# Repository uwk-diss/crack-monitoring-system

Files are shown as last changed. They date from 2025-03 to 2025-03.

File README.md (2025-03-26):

# Open Source Low-cost IoT Crack Monitoring Sensor System

## Introduction

Cracks in buildings and infrastructure can pose safety risks if left unmonitored. Traditional commercial solutions can be prohibitively expensive, so this project was created to provide a cost-effective alternative. Here, you will find open-source hardware designs, firmware, and backend software needed to set up a complete, network-connected crack monitoring solution.

This project provides two different sensor designs for monitoring the width of existing cracks:
- A 3D-printable long range **draw-wire sensor** using a magnetic encoder and custom PCB.
- A **digital dial indicator sensor (shahe sensor)** offering reliable and accurate readings using a off the shelf digital dial indictor of the brand SHAHE.

Both sensors are designed to operate on battery power with LoRaWAN connectivity, and a corresponding backend is provided to visualize data in real-time using MQTT, InfluxDB, and Grafana. The goal is to make structural health monitoring both accessible and affordable.

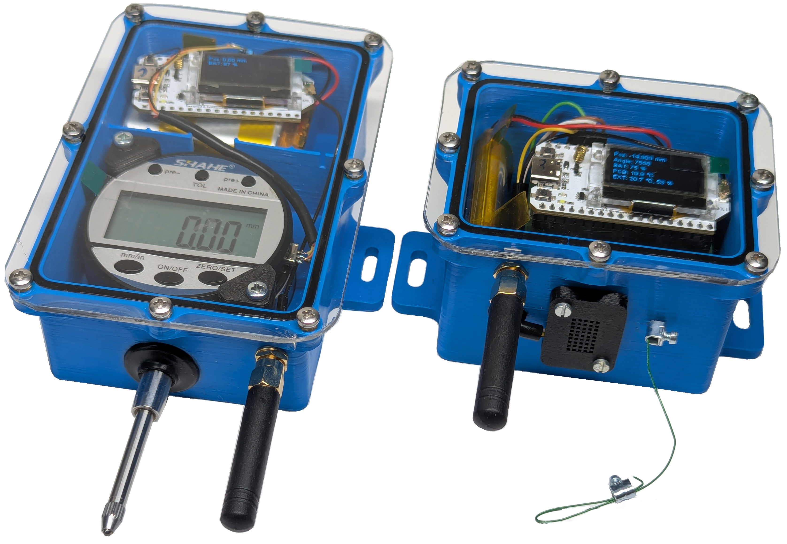
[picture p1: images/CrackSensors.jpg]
Shahe digital gauge sensor (left) and Draw-wire sensor (right)

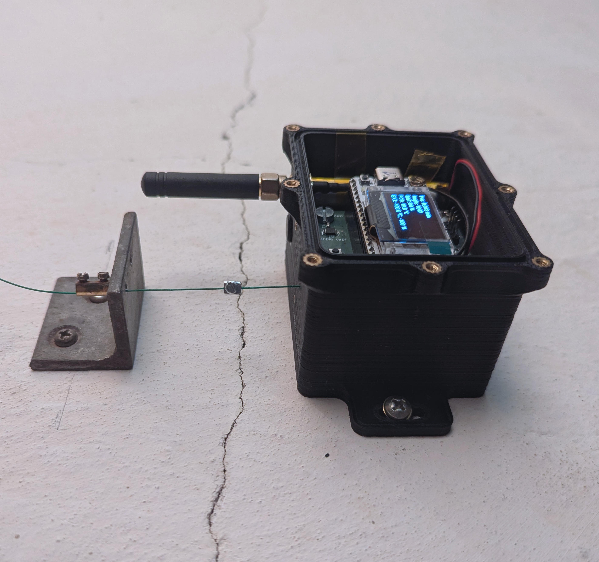
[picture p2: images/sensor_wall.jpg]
Sensor mounted on a wall


## Hardware Overview and Specifications

Block diagram of hardware

The main communication module for both sensors is the **Heltec WiFi LoRa 32 (V3)**, which supports a deep sleep current of approximately **21 µA**. Beyond the LoRa radio, it also integrates an OLED display and a Li-ion battery charging and protection circuit.

For the **draw-wire sensor**, the temperature, humidity, and hall angle sensors connect via I²C. Meanwhile, the **digital dial indicator sensor** uses a proprietary serial protocol, read through a customized USB OTG cable.

### Sensor specs:

| Parameter | Draw-Wire Sensor | SHAHE Sensor |
|---|---|---|
| Measurement Range | 55 mm | 26 mm |
| Resolution | 16 µm | 10 µm |
| Absolute Accuracy | 96 µm | 10 µm |
| Repeatability | ±16 µm | ±10 µm |
| Temperature Dependence  | 5 µm/°C* | 0 µm/°C |
| Position drift | yes** | no |
| Battery Life | ~11 months | ~11 months |
| Material Cost (excluding VAT) | ~€48.50 | ~€65 |

*Temperature compensation of the draw-wire sensor is not implemented yet.

**During a 7-week long-term test, the draw-wire sensor exhibited a permanent position offset of more than 0.1 mm. This requires further investigation.

## Communication and Backend
The sensor data is transmitted hourly via LoRaWAN. [The Things Network](https://www.thethingsnetwork.org/) can be used as a provider for the LoRaWAN backend, or a self-hosted version such as [Chripstack](https://www.chirpstack.io/).
The data must be transferred from the LoRaWAN backend to a dedicated server via MQTT and stored in a database ([InfluxDB](https://github.com/influxdata/influxdb)). A Grafana dashboard is used to visualise the data.

Block diagram of hardware

## Repository Overview

- **draw-wire-sensor/**  
  Contains the 3D-printable hardware design, a PCB project, and the firmware source code for the draw-wire sensor.
- **shahe-sensor/**  
  Provides the hardware documentation and firmware to integrate the commercially available Shahe digital indicator.
- **backend/**  
  Contains Docker configurations, scripts, and a Grafana dashboard for storing, processing, and visualizing crack measurements.

More information and detailed assembly as well as usage instructions can be found in the respective subfolders.

## Credits

We would like to acknowledge the following open-source software libraries and frameworks that have made this project possible:
- [heltec_esp32_lora_v3 by Rop Gonggrijp](https://github.com/ropg/heltec_esp32_lora_v3) for providing the easy to use Heltec WiFi LoRa 32(V3) library
- [LoRaWAN_ESP32 by Rop Gonggrijp](https://github.com/ropg/LoRaWAN_ESP32) for LoRaWAN persistence handling
- [RadioLib](https://github.com/jgromes/RadioLib) for LoRaWan communication handling
- [PlatformIO](https://platformio.org/) for easy firmware development and deployment
- [Arduino Core](https://github.com/arduino/Arduino) for base microcontroller support
- [Docker](https://www.docker.com/) for containerization
- [Grafana](https://grafana.com/) for data visualization
- [InfluxDB](https://www.influxdata.com/) for time-series database storage

## Disclaimer

This Project is not completely finalized and may undergo changes. Use at your own risk.

## License

This project is available under the [MIT License](./LICENSE).

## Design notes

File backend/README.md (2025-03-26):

# How to Deploy the Crack Monitoring Backend
This manual includes the registration of the Sensors and the setup of the MQTT-bridge, InfluxDB database and Grafana using Docker.

## 1. Register End Devices in The Things Network

1. Sign up at https://www.thethingsnetwork.org/login/  
2. Register each device with the following configuration:  
   - **Input method:** Enter end device specifics manually  
   - **Frequency plan:** Europe 868‑870 MHz (SF9 for RX2 recommended)  
   - **LoRaWAN version:** 1.1.0  
   - **Regional Parameters version:** RP001 Regional Parameters 1.1 revision B  
   - **JoinEUI:** All zeros → Confirm  
   - **DevEUI:** Generate  
   - **AppKey:** Generate  
   - **NwkKey:** Generate  
   - **End device ID:** e.g., `crackmon-01`  

3. Update `grafana/provisioning/dashboards/dashboards/CrackMonitoring.json` so device IDs (`crackmon-01`, `crackmon-02`, etc.) match your registered sensor IDs.

Detailed reference: https://github.com/jgromes/RadioLib/wiki/LoRaWAN:-Device-setup-on-TTN

### Create Payload Formatter

Adapt this JavaScript function so it fits the Payload and paste it in TTN Console → Payload Formats → Decoder:

```js
function decodeUplink(input) {
    const bytes = input.bytes;
    function int16(msb, lsb) {
        let value = (msb << 8) | lsb;
        return value & 0x8000 ? value - 0x10000 : value;
    }
    return {
        data: {
            pos: int16(bytes[0], bytes[1]) / 1000,
            temp_ext: int16(bytes[2], bytes[3]) / 100,
            hum_ext: bytes[4],
            temp_pcb: int16(bytes[5], bytes[6]) / 100,
            battery: bytes[7],
            angle: int16(bytes[8], bytes[9])
        }
    };
}
```

Test with hex payload `F6D90A271E0B156323`. Expected output:

```json
{
  "pos": -2.343,
  "angle": 8960,
  "temp_ext": 25.99,
  "hum_ext": 30,
  "temp_pcb": 28.37,
  "battery": 99
}
```

## 2. Create `.env` File

In the backend directory create a file named `.env` with these variables:

```bash
MQTT_USERNAME=your_ttn_mqtt_username
MQTT_PASSWORD=your_ttn_mqtt_token

INFLUXDB_INIT_USERNAME=admin
INFLUXDB_INIT_PASSWORD=<your-password>
INFLUXDB_INIT_ADMIN_TOKEN=<your-token>

GRAFANA_ADMIN_USER=admin
GRAFANA_ADMIN_PASSWORD=<your-password>
```

Generate a secure InfluxDB token with:

```bash
python3 - <<<'import secrets; print(secrets.token_hex(32))'
```

## 3. Build and Start Docker Containers

```bash
docker-compose build
docker-compose up -d
```

## 4. Test Downlink

Simulate uplink in TTN Console using payload `F6D90A271E0B156323`
```bash
docker logs mqtt_to_influxdb
```

Check InfluxDB at http://localhost:8086

## 5. Configure Grafana
1. At <http://localhost:3000/> in *Connections/Data sources* select *InfluxDB* and manually add the influxdb token
2. In the dashboard edit each panel and click refresh in the 'Query inspector' to initially load the data
3. Add your own panels

## Troubleshooting
Check logs:
```
docker logs mqtt_to_influxdb
docker logs grafana
docker logs influxdb
```

Reset all volumes (deletes all saved data/changes in InfluxDB and Grafana container!):
```
docker-compose down -v
```

Remove container before recreating:
```
docker container rm mqtt_to_influxdb
```

Rebuild single container after changes:
```
docker compose build mqtt_to_influxdb
docker compose up -d  mqtt_to_influxdb
```

RaspberryPi: Add `platform: linux/arm64` under Grafana and InfluxDB services in `docker-compose.yml`.

## File Transfer to Raspberry Pi

```bash
scp -r ./backend pi@10.0.0.71:/home/pi/
scp ./mqtt_to_influxdb.py pi@10.0.0.71:/home/pi/backend/
```

## Backup & Restore InfluxDB

```bash
# Backup
docker ps
docker exec -it <container_id> influx backup /opt/influxdb/data/backup
docker cp <container_id>:/opt/influxdb/data/backup ~/backend/backup

# Transfer to local
scp -r pi@raspberrypi.local:/home/pi/backend/backup ~/influx_backup

# Restore
docker cp ~/influx_backup/ <container_id>:/home/user/
docker exec -it <container_id> influx restore /home/user/
```

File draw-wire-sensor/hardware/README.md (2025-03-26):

# Draw-Wire Crack Sensor Hardware

## Draw-Wire Sensor
[3D-model Onshape Link](https://cad.onshape.com/documents/727012fc8109642ef30e330c/w/04f195b811331b23b33eb80b/e/cc3c6dd55492ae3cabf4f177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)

### Functionality
draw-wire sensor schema
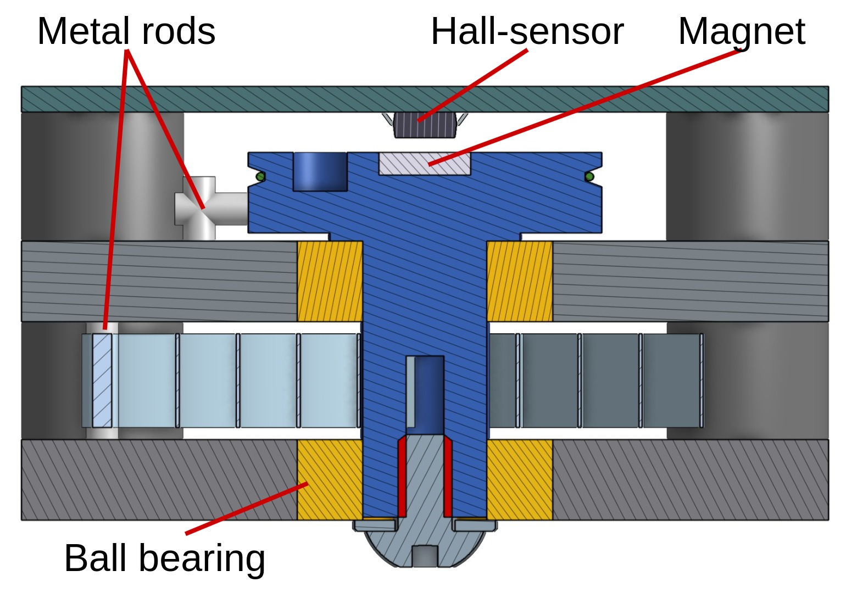
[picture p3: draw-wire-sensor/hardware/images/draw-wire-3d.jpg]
sensor sectional view


### Materials
- 3D printed parts (Spool, BearingHolder1, BearingHolder2)
- Hall sensor PCB
- 8x16x5 mm ball bearing
- 0.2x5x420 mm spring
- 2 mm steel rod (2 pcs. 12 mm, 2 pcs. 8 mm) e.g. a bicycle spoke
- 0.5 mm steel wire (100 mm)
- Diametrical magnet (6 mm diameter, 1 mm thick)
- M4x8 button head screw and M4 washer
- M4x30 screws (4 pcs.)
- Single screw terminal as wire stopper

### Tools
- 3D Printer
- Soldering iron, solder, flux, and solder wick
- Round-nose pliers
- Tongue-and-groove pliers
- 2 mm drill bit

### Assembly
1. Assemble the PCB.
2. Print the parts (100% infill, 0.1 mm layer height).
3. Insert (and glue) the magnet into the spool with maximum precision.
4. Press-fit the bearings into the bearing-holders.
5. Press-fit the steel rods into the spool and upper bearing-holder (you may need to slightly drill out the holes beforehand).
6. Bend the spring as shown in the picture using round-nose pliers.
7. Insert the spool and then the spring.
8. Add the lower bearing-holder and slightly tighten the button head screw on the bottom of the spool.

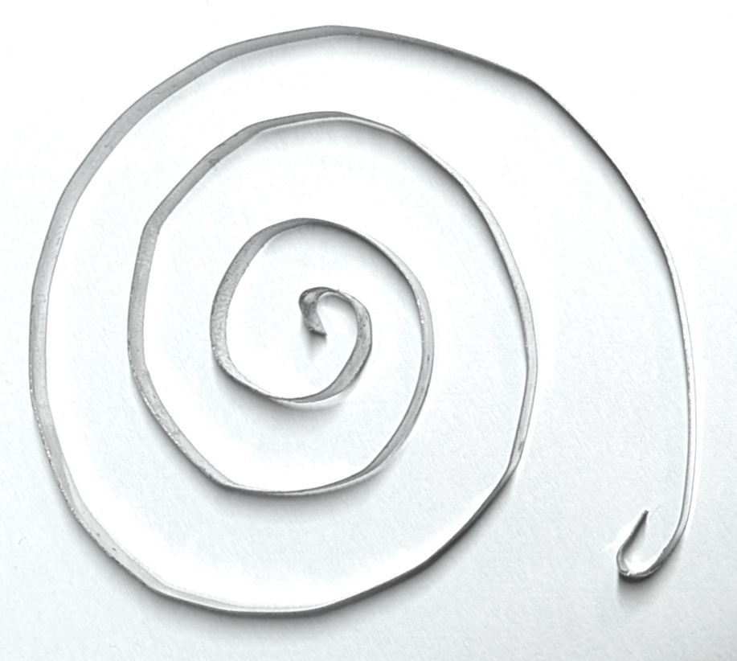
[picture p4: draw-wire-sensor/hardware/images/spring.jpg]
spring

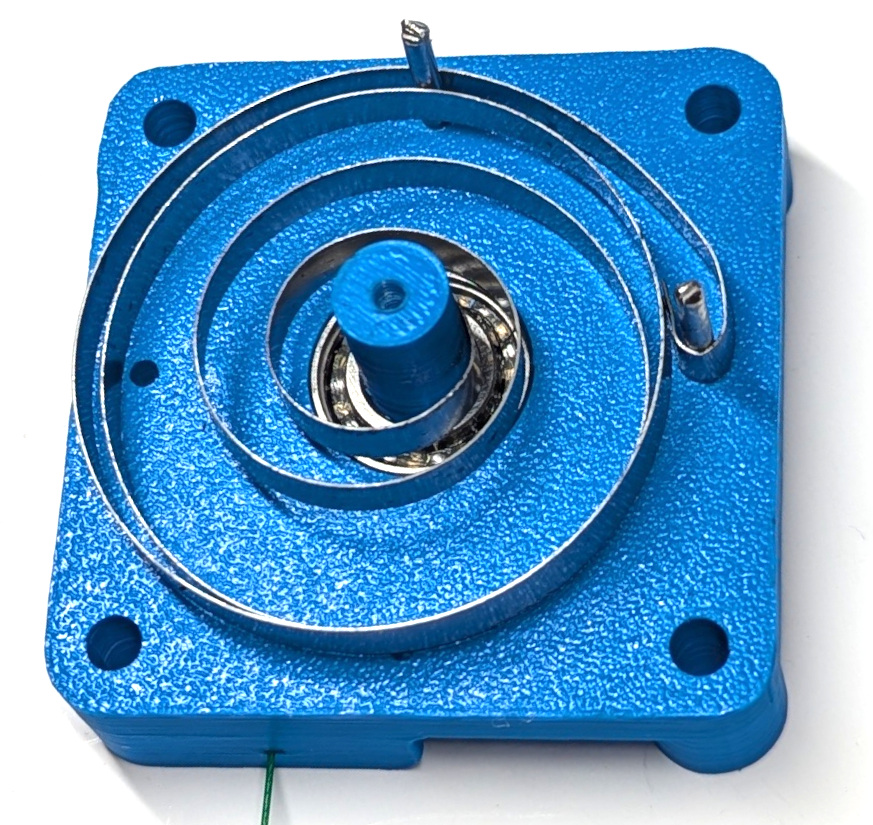
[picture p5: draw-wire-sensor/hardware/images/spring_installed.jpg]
spring installed


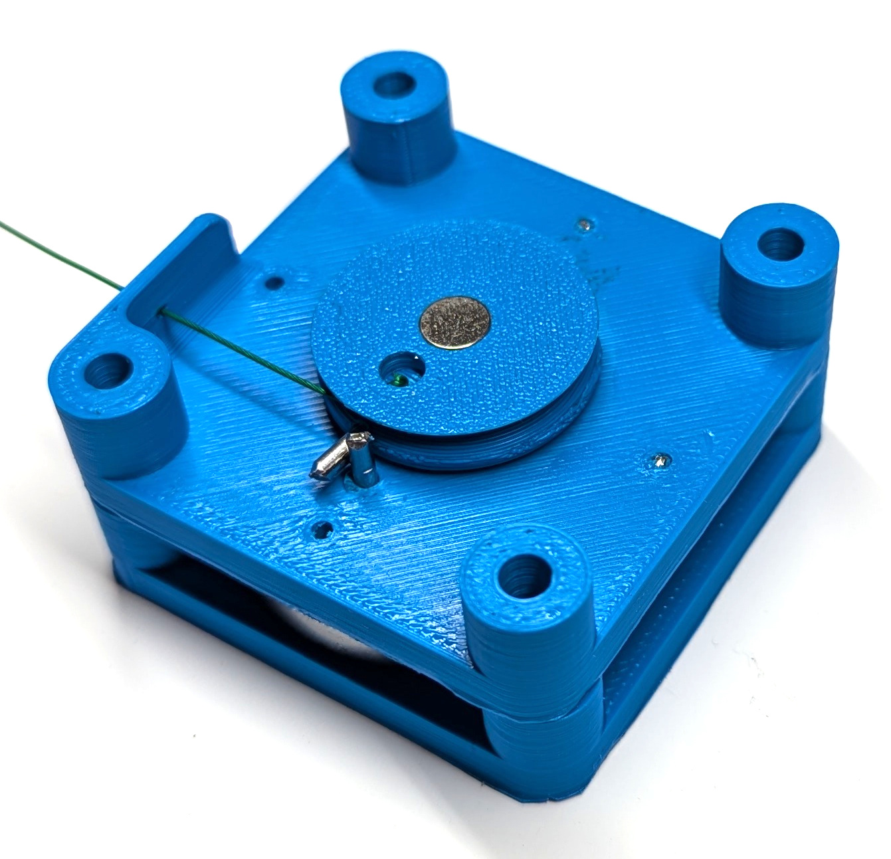
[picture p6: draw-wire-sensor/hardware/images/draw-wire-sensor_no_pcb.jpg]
sensor without pcb

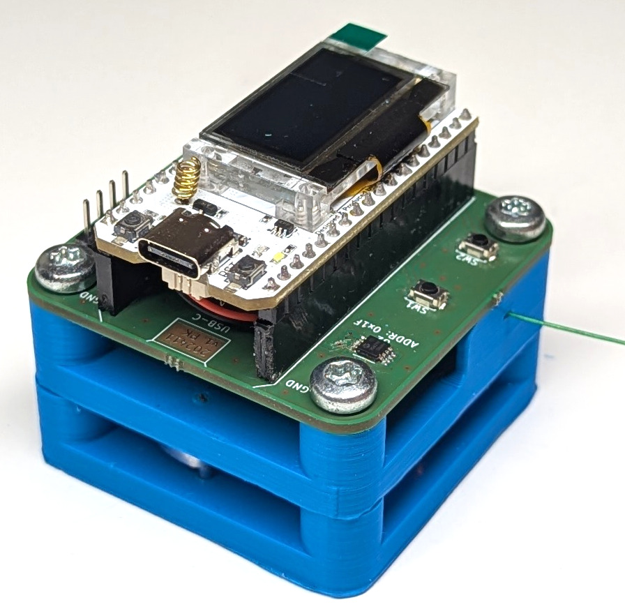
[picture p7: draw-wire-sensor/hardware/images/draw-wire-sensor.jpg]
sensor with pcb and microcontroller


## Enclosure
[3D-model Onshape Link](https://cad.onshape.com/documents/93da92487be01dacccf96228/w/5f335a3fbf208dbb23918342/e/3e6e6e181994376e8e597439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)

### Materials
- 3D printed enclosure (ASA)
- Acrylic glass (2 mm) or 3D printed lid
- Short M3 inserts (8 pcs.)
- Short M4 inserts (4 pcs.)
- Short M2 inserts (2 pcs.)
- M3x6 screws (8 pcs.)
- M2x5 screws (2 pcs.)
- EPDM sealing cord (255 mm)
- Rubber grommet
- Acrylic paint / conformal coating / 3D-print sealant
- Silicone grease

### Tools
- 3D Printer
- Soldering iron
- 3.5 mm drill bit and drill
- Cutter knife

### Assembly
1. Print the enclosure (100% infill, 0.15 mm layer height).
2. Seal the print with spray paint.
3. Print the lid template (0.5 mm).
4. Transfer the template to acrylic glass and cut out the outlines.
5. Drill 3.5 mm screw holes in the lid.
6. Use a soldering iron to melt in the inserts.
7. Lubricate the seal and the grommet with silicone grease and insert them.

## Additional information
- With a longer string multiple parallel cracks can be monitored at once

## Future Improvements / To-Dos / Ideas
- Create a parametric 3D design for the draw-wire sensor and the enclosure using FreeCAD.
- Add a 3D printable adapter for standalone use of the draw-wire sensor with standard AS5600/MT6701 modules.
- Investigate the impact of hall sensor magnet alignment on accuracy and hysteresis.
- Further investigate the permanent drift of the sensor position

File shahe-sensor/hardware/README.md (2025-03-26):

# Digital Dial Indicator Crack Sensor Hardware

[3D-model Onshape Link](https://cad.onshape.com/documents/177fcd6626cff4e7ae1118a5/w/60c44c86a3964531458f62a3/e/0062c1a0376e6109ae3408a2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)

### Materials
- SHAHE Digital Dial Indicator 5307A-10/25 <https://aliexpress.com/item/32663445499.html>
- Heltec Wifi LoRa 32 V3
- Angled Mini-USB-OTG cable or Mini-USB connector with ID-pin
- 100k resistor (2 pcs.)
- 3D printed enclosure (ASA)
- 3D printed brackets (2 pcs.)
- Acrylic glass (2 mm) or 3D printed lid
- Short M3 inserts (10 pcs.)
- M3x6 screws (8 pcs.)
- M3x30 screws (2 pcs.)
- EPDM sealing cord (340 mm)
- Rubber grommet (od 20 mm, id 7 mm)
- Acrylic paint / conformal coating / 3D-print sealant
- Silicone grease

### Tools
- 3D Printer
- Soldering iron
- 3.5 mm drill bit and drill
- Cutter knife

### Assembly
1. Print the enclosure (100% infill, 0.15 mm layer height).
2. Seal the print with spray paint.
3. Print the lid template (0.5 mm).
4. Transfer the template to acrylic glass and cut out the outlines.
5. Drill 3.5 mm screw holes in the lid.
6. Use a soldering iron to melt in the inserts.
7. Lubricate the seal and the grommet with silicone grease and insert them.
8. Cut off the USB-A socket of the OTG-cable and solder the wires to the Heltec microcontroller with the resistors in series as shown in the picture.
9. Insert the SHAHE indicator and secure it with the brackets and M3x30 screws. Use silicone grease to seal the grommet.

pin out diagram

## Additional information
- The tip of the shaft of the dial indicator can be unscrewed to extend it with suitable spacers.
- Instead of the USB-OTG-cable wires can be soldered directly to a 5 pin Mini-USB connector.

## Future Improvements / To-Dos / Ideas
- Create a parametric 3D design for the enclosure using FreeCAD.
- Extend enclosure so OTG cable fits in
- Add holes for grommet and inserts for the external temperature sensor

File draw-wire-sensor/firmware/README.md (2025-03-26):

# Draw-Wire Sensor Firmware
## Used librarys
- heltec_esp32_lora_v3 <https://github.com/ropg/heltec_esp32_lora_v3>
- LoRaWAN_ESP32 <https://github.com/ropg/LoRaWAN_ESP32>

## Flowcharts
### Programm flow
flowchart

### Calibration flow: 
flowchart

## Future Improvements
- Add temperature compensation
- Implement manual send and receive and light sleep in between to significantly reduce the power consumption like discussed here: <https://github.com/jgromes/RadioLib/discussions/964>

## Troubleshooting
- Add just the firmware folder to to PlatformIO workspace
- If the project is not listed in the PIO environment list -> F1 -> PlatformIO: Rebuild IntelliSense Index

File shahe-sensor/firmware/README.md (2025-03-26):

# Digital Dial Indicator Sensor Firmware
## Used librarys
- heltec_esp32_lora_v3 <https://github.com/ropg/heltec_esp32_lora_v3>
- LoRaWAN_ESP32 <https://github.com/ropg/LoRaWAN_ESP32>

## Programm flow
flowchart

## Future Improvements
- Implement manual send and receive and light sleep in between to significantly reduce the power consumption like discussed here: <https://github.com/jgromes/RadioLib/discussions/964>

## Troubleshooting
- Add just firmware folder to to PlatformIO workspace
- If the project is not listed in the PIO environment list -> F1 -> PlatformIO: Rebuild IntelliSense Index

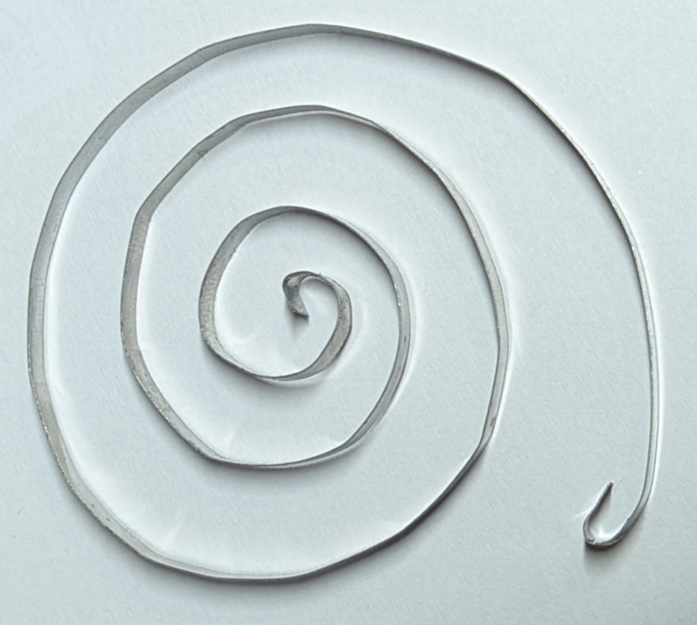
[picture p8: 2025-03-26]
images/spring.jpg

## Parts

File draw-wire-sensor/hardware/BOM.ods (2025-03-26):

Name | Quantity | Unit price | Price | Purpose | Comment | Link
Diametral magnet 6x1 mm | 1 | 0,31 € | 0,31 € | Draw-Wire-Sensor |  | https://www.amazon.de/Diametral-Magnetisierter-Neodym-Handwerk-Modellherstellung/dp/B003MWBZ2U
Spring | 1 | 0,50 € | 0,50 € | Draw-Wire-Sensor
Ball bearing 688-2RS | 2 | 0,67 € | 1,34 € | Draw-Wire-Sensor | 8x16x5 mm | https://www.amazon.de/688-2RS-Kugellager-Miniatur-Rillenkugellager-Doppeltes-Versiegeltes/dp/B07D3KB99Q
Metal rod 2 mm | 4 | 0,10 € | 0,40 € | Draw-Wire-Sensor | bicycle spoke, 12 mm, 2x8 mm
Steel cord 0,5 mm | 1 | 0,35 € | 0,35 € | Draw-Wire-Sensor | 50 cm | https://www.amazon.de/Angelschnur-Drahtf%C3%BChrer-Edelstahl-Crimps-%C3%84rmeln/dp/B07B4CJXRN (https://www.amazon.de/Angelschnur-Drahtführer-Edelstahl-Crimps-Ärmeln/dp/B07B4CJXRN)
3D-print draw wire sensor | 1 | 1,53 € | 1,53 € | Draw-Wire-Sensor | 32,5 g
EPDM sealing cord 2 mm | 1 | 0,50 € | 0,50 € | Enclosure | 254 mm | https://www.amazon.de/sourcing-map-Wetterdichtung-Schaumstoffschl%C3%A4uche-Heimdichtung/dp/B0BKGNSDWJ
M3x6 screws | 8 | 0,02 € | 0,16 € | Enclosure |  | https://www.schraubenhandel24.de/schrauben/gewindeschrauben/zylinderschrauben/din-912/din-912-zylinderschrauben-isk-edelstahl-a4/din-912-zylinderschrauben-ede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
Rubber gasket | 1 | 0,10 € | 0,10 € | Enclosure |  | https://www.amazon.de/KUBOWAI-Gummi-Kabelt%C3%BCllen-Set-Gummit%C3%BCllen-Set-Steckert%C3%BClle-Kabelverbindern/dp/B0C1CL8B8S
M3 short inserts | 8 | 0,07 € | 0,59 € | Enclosure |  | https://www.amazon.de/3D-Druck-Messing-Muttern-M3-Gewindeeinsatz-Messingmuttern-Gewindeeinsatz-Einpressmutter-Automobil-Kunststoffschale/dp/B0BTYF2MMD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
M4 short inserts | 4 | 0,19 € | 0,76 € | Enclosure |  | https://www.amazon.de/Gewindeeinsatz-Gewindebuchsen-Einpressmutter-Kunststoffteile-Ultraschall/dp/B09MTTC7S9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
M4x30 screws | 4 | 0,10 € | 0,40 € | Enclosure |  | https://www.schraubenhandel24.de/schrauben/gewindeschrauben/zylinderschrauben/din-912/din-912-zylinderschrauben-isk-stahl-8-8-verzinkt/din-912-zylinderschraub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
Acrylic lid 2 mm | 1 | 2,00 € | 2,00 € | Enclosure
Silicone grease | 1 | 0,10 € | 0,10 € | Enclosure
3D-print enclosure | 1 | 3,92 € | 3,92 € | Enclosure | 67 g
AS5600 | 1 | 2,38 € | 2,38 € | PCB |  | https://www.mouser.at/ProductDetail/ams-OSRAM/AS5600-ASOM?qs=KTMMzrZdriG6aU1h9lJCUQ%3D%3D
C 100nF 0603 | 3 | 0,10 € | 0,30 € | PCB |  | https://www.mouser.at/ProductDetail/KYOCERA-AVX/0603ZG104ZAT2A?qs=XWDBCzcA0Tke70DI9cEVbA%3D%3D
JST PH B2B 2mm | 1 | 0,13 € | 0,13 € | PCB |  | https://www.digikey.at/de/products/detail/jst-sales-america-inc/B2B-PH-K-S/926611#
MCP9808 | 1 | 1,30 € | 1,30 € | PCB |  | https://www.mouser.at/ProductDetail/Microchip-Technology/MCP9808T-E-MS?qs=fgHA1UgJI8BYolGts7svKQ%3D%3D
Picoblade 53047-0210 | 1 | 0,11 € | 0,11 € | PCB |  | https://www.mouser.at/ProductDetail/Molex/53047-0210?qs=M5Ic86%252BuP8b8FQrTwriyOw%3D%3D
Pinheader 4 pins | 1 | 0,74 € | 0,74 € | PCB |  | https://www.amazon.de/IZOKEE-M%C3%A4nnlich-Stiftleiste-Buchsenleiste-Lochrasterplatine/dp/B07DBY753C (https://www.amazon.de/IZOKEE-Männlich-Stiftleiste-Buchsenleiste-Lochrasterplatine/dp/B07DBY753C)
R 0603 4k7 | 2 | 0,09 € | 0,19 € | PCB |  | https://www.mouser.at/ProductDetail/Vishay-Dale/CRCW06034K70FKEAC?qs=E3Y5ESvWgWMdaA4%252BnoVN0A%3D%3D
SKRKAEE020 Button | 2 | 0,20 € | 0,40 € | PCB |  | https://www.mouser.at/ProductDetail/Alps-Alpine/SKRKAEE020?qs=MrosSN5%252BUQW89XjXIp8Ugw%3D%3D
PCB | 1 | 0,65 € | 0,65 € | PCB | JLCPCB
Helltec Wifi LoRa V3 | 1 | 24,25 € | 24,25 € |  |  | https://www.amazon.de/APKLVSR-Entwicklungsplatine-Entwicklungsboard-Dual-Core-Bluetooth/dp/B0CKRGVLK4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
LiPo 2000 mAh | 1 | 6,75 € | 6,75 € |  |  | https://www.amazon.de/Seamuing-Schutzplatine-Isolierband-1-25-Stecker-ESP32-Entwicklungsplatine/dp/B08TQSC5G9
SHT45 external tem/hum sensor | 1 | 4,92 € | 4,92 € |  |  | https://www.mouser.at/ProductDetail/Adafruit/5665?qs=mELouGlnn3dyBBHYyvKU4A%3D%3D
Cable for external sensor | 1 | 0,20 € | 0,20 € |  | 80 mm
 |  | Sum; | 55,08 €

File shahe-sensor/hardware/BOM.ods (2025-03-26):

Name | Quantity | Unit price | Price | Purpose | Comment | Link
3D-print | 1 | 4,95 € | 4,95 € | Enclosure | ASA | https://filamentworld.de/shop/special-filament/asa-filament/material4print-asa-filament-signalweiss-1-75-mm/
Acrylic lid 2 mm | 1 | 2,00 € | 2,00 € | Enclosure
EPDM sealing cord 2 mm | 1 | 0,50 € | 0,50 € | Enclosure | 340 mm | https://www.amazon.de/sourcing-map-Wetterdichtung-Schaumstoffschl%C3%A4uche-Heimdichtung/dp/B0BKGNSDWJ
M3 short inserts | 8 | 0,07 € | 0,59 € | Enclosure |  | https://www.amazon.de/3D-Druck-Messing-Muttern-M3-Gewindeeinsatz-Messingmuttern-Gewindeeinsatz-Einpressmutter-Automobil-Kunststoffschale/dp/B0BTYF2MMD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
M3x30 screws | 2 | 0,04 € | 0,08 € | Enclosure |  | https://www.schraubenhandel24.de/schrauben/gewindeschrauben/ry-iso-4762-zylinderschrauben-isk-edelstahl-a2-m3x30
M3x6 screws | 8 | 0,02 € | 0,16 € | Enclosure |  | https://www.schraubenhandel24.de/schrauben/gewindeschrauben/zylinderschrauben/din-912/din-912-zylinderschrauben-isk-edelstahl-a4/din-912-zylinderschrauben-ede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
Rubber gasket | 2 | 0,10 € | 0,20 € | Enclosure |  | https://www.amazon.de/KUBOWAI-Gummi-Kabelt%C3%BCllen-Set-Gummit%C3%BCllen-Set-Steckert%C3%BClle-Kabelverbindern/dp/B0C1CL8B8S
Silicone grease | 1 | 0,10 € | 0,10 € | Enclosure
100k resistors | 2 | 0,10 € | 0,20 €
Cable for external sensor | 1 | 0,20 € | 0,20 € |  | 80 mm
Helltec Wifi LoRa V3 | 1 | 24,25 € | 24,25 € |  |  | https://www.amazon.de/APKLVSR-Entwicklungsplatine-Entwicklungsboard-Dual-Core-Bluetooth/dp/B0CKRGVLK4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
LiPo-battery 2000 mAh | 1 | 6,75 € | 6,75 € |  |  | https://www.amazon.de/Seamuing-Schutzplatine-Isolierband-1-25-Stecker-ESP32-Entwicklungsplatine/dp/B08TQSC5G9
Mini USB OTG | 1 | 2,00 € | 2,00 € |  | right angle | https://de.aliexpress.com/item/1005001604972330.html https://www.mouser.at/ProductDetail/TE-Connectivity/1734205-1?qs=o4qE4s2E%252BcwHLCQYxSm%252B8w%3D%3D
SHAHE 5307A-10/25 | 1 | 30,00 € | 30,00 € |  |  | https://de.aliexpress.com/item/32663445499.html
SHT45 external tem/hum sensor | 1 | 4,92 € | 4,92 € |  |  | https://www.mouser.at/ProductDetail/Adafruit/5665?qs=mELouGlnn3dyBBHYyvKU4A%3D%3D
Acrylic paint
 |  | Sum: | 76,90 €

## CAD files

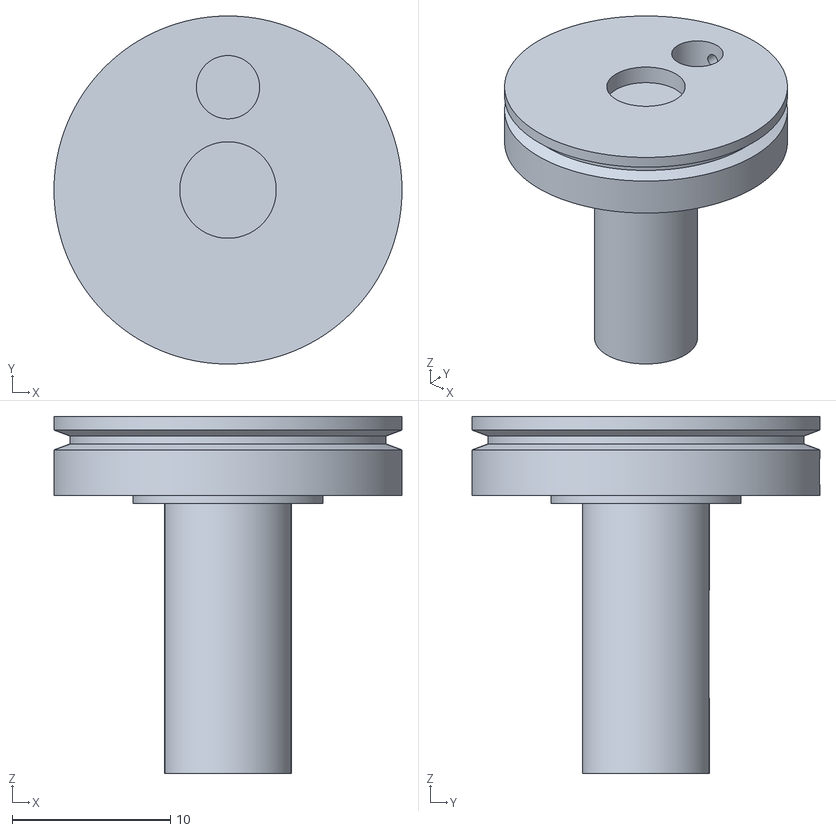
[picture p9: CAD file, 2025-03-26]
draw-wire-sensor/hardware/3d models/Spool.stl
22.0 x 22.0 x 22.6

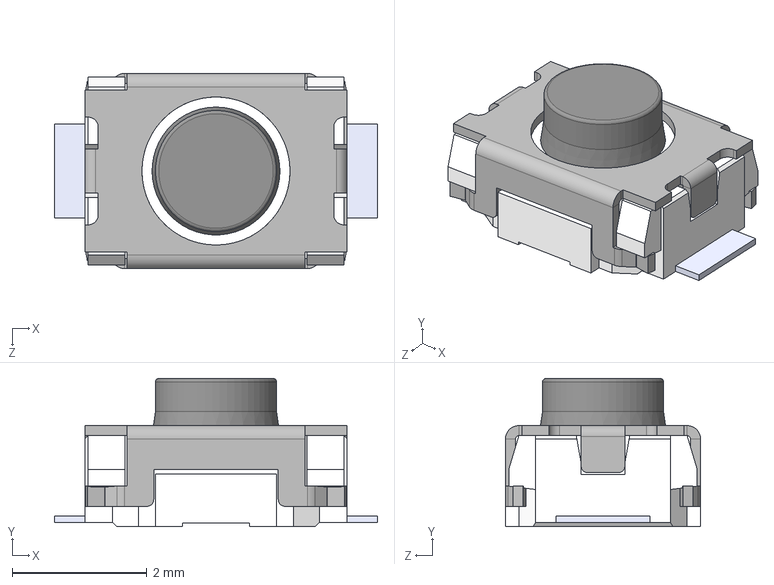
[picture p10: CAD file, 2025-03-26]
draw-wire-sensor/hardware/pcb/3d_models/SKRKAHE020--3DModel-STEP-56544.STEP
4.80 x 2.20 x 2.90 mm

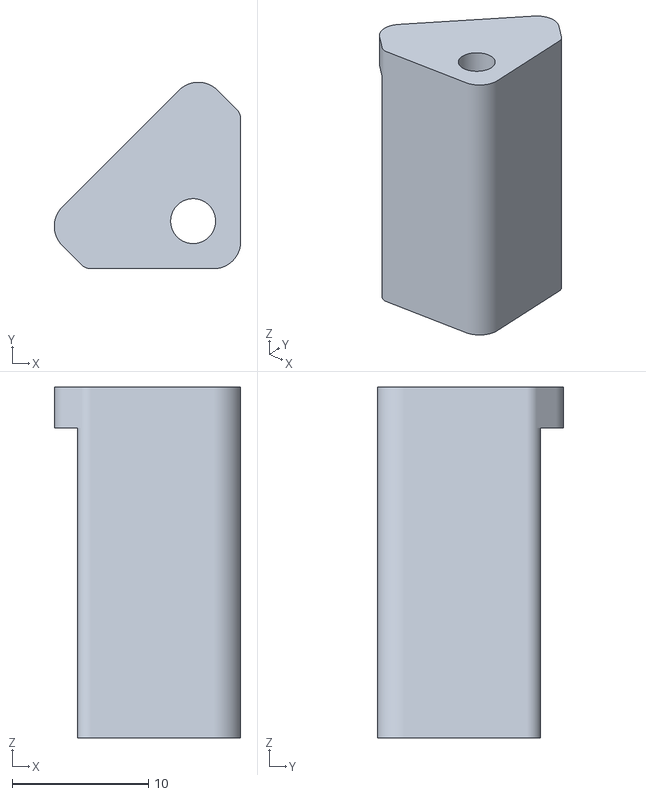
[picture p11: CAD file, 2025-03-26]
shahe-sensor/hardware/Bracket.stl
13.7 x 13.7 x 25.8

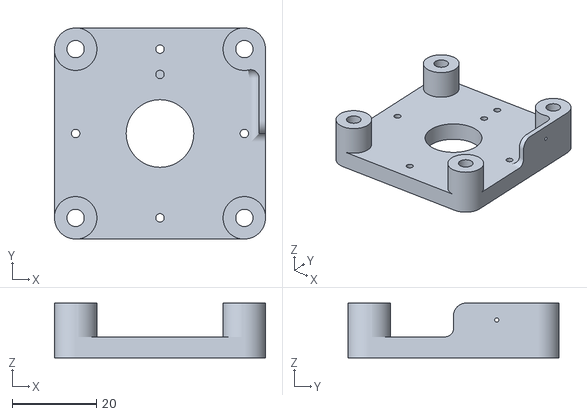
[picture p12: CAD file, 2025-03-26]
draw-wire-sensor/hardware/3d models/BearingHolder1.stl
50.0 x 50.0 x 13.0

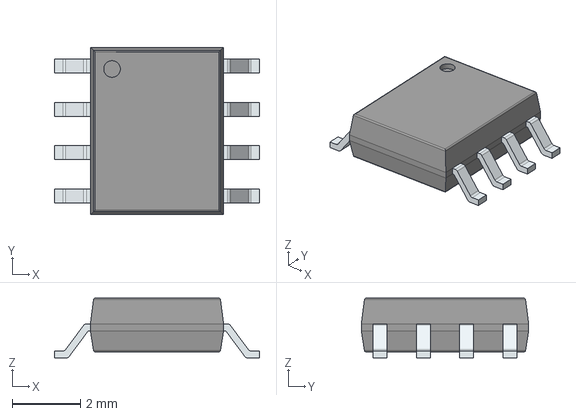
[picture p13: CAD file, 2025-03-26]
draw-wire-sensor/hardware/pcb/3d_models/AS5600L-ASOM.stp
6.00 x 4.90 x 1.75 mm
PinsArrayLR

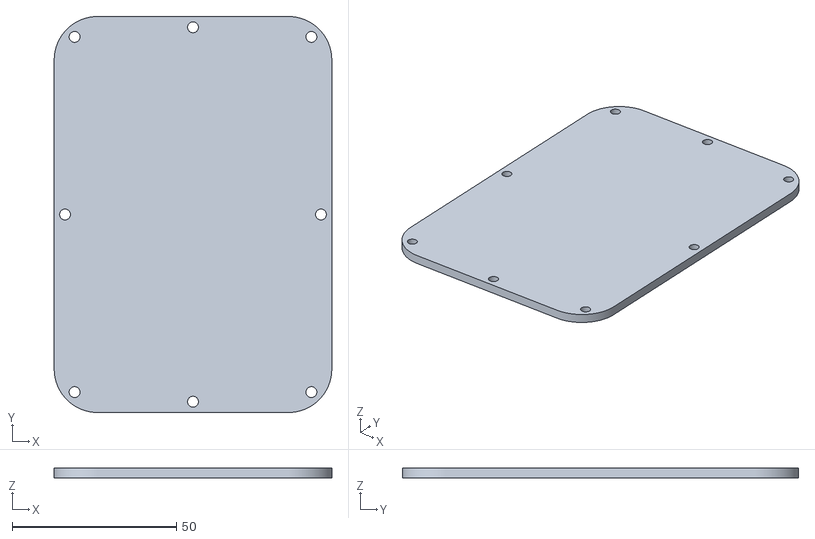
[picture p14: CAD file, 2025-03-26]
shahe-sensor/hardware/Lid.stl
84.4 x 120.4 x 3.00

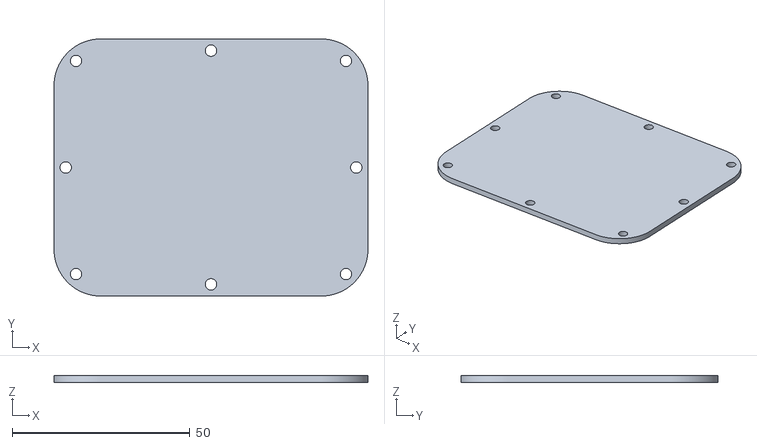
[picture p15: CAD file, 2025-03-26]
draw-wire-sensor/hardware/3d models/Lid.stl
88.4 x 72.4 x 2.00

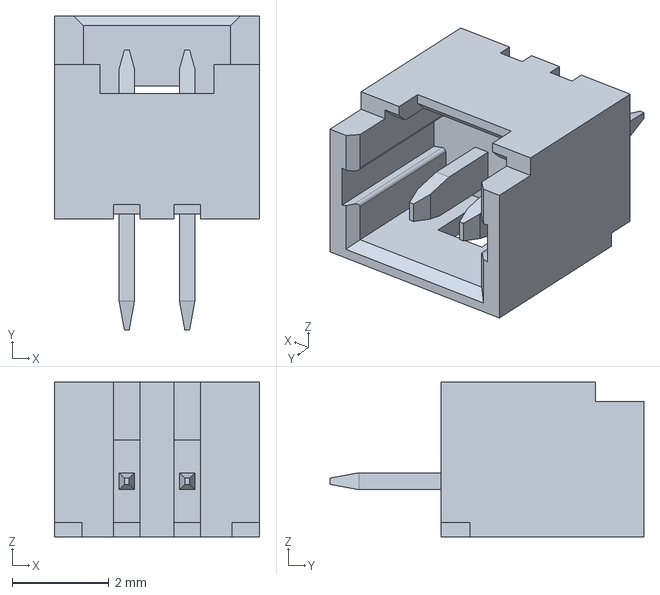
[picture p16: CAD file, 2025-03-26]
draw-wire-sensor/hardware/pcb/3d_models/picoblade_2p.stp
4.25 x 6.50 x 3.20 mm

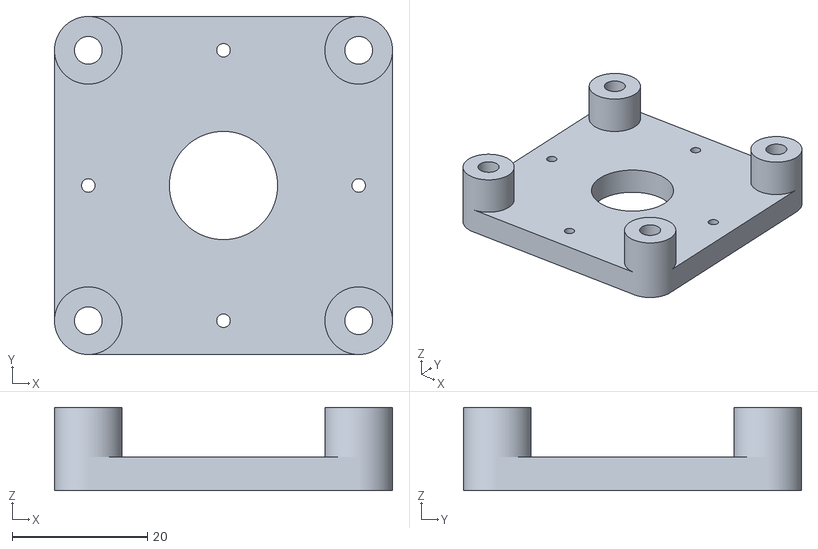
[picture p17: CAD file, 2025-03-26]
draw-wire-sensor/hardware/3d models/BearingHolder2.stl
50.0 x 50.0 x 12.3

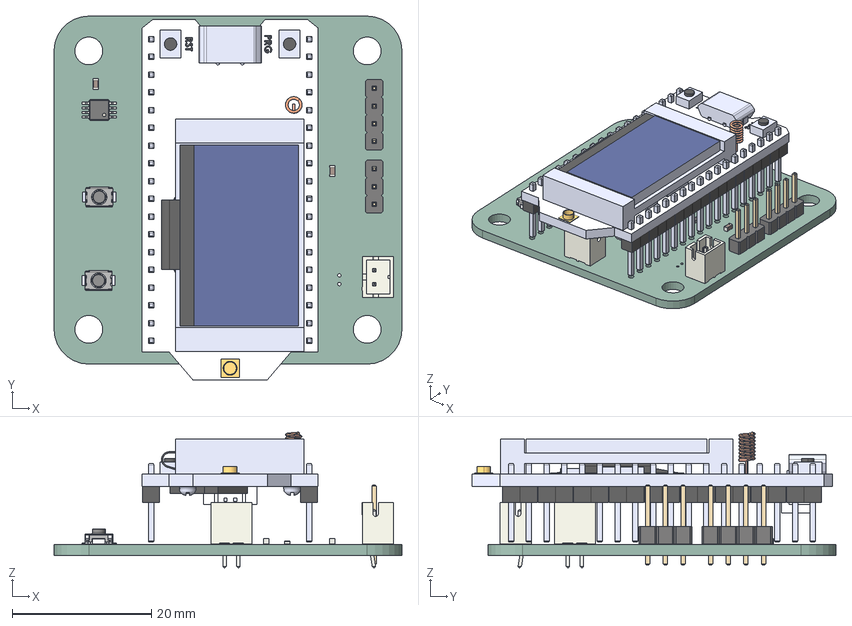
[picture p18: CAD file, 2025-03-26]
draw-wire-sensor/hardware/pcb/3d_models/crack-draw-wire-pcb.step
50.0 x 52.3 x 19.5 mm
C_0603_1608Metric x 3
R_0603_1608Metric
SKRKAHE020 x 2
PinHeader_1x04_P254mm_Vertical
PinHeader_1x03_P254mm_Vertical
JST_B2B_PH_K x 2
MSOP_8_3x3mm_P065mm
heltec_wifi_32_asm2
_autosave-crack_monitoring_minimal_PCB

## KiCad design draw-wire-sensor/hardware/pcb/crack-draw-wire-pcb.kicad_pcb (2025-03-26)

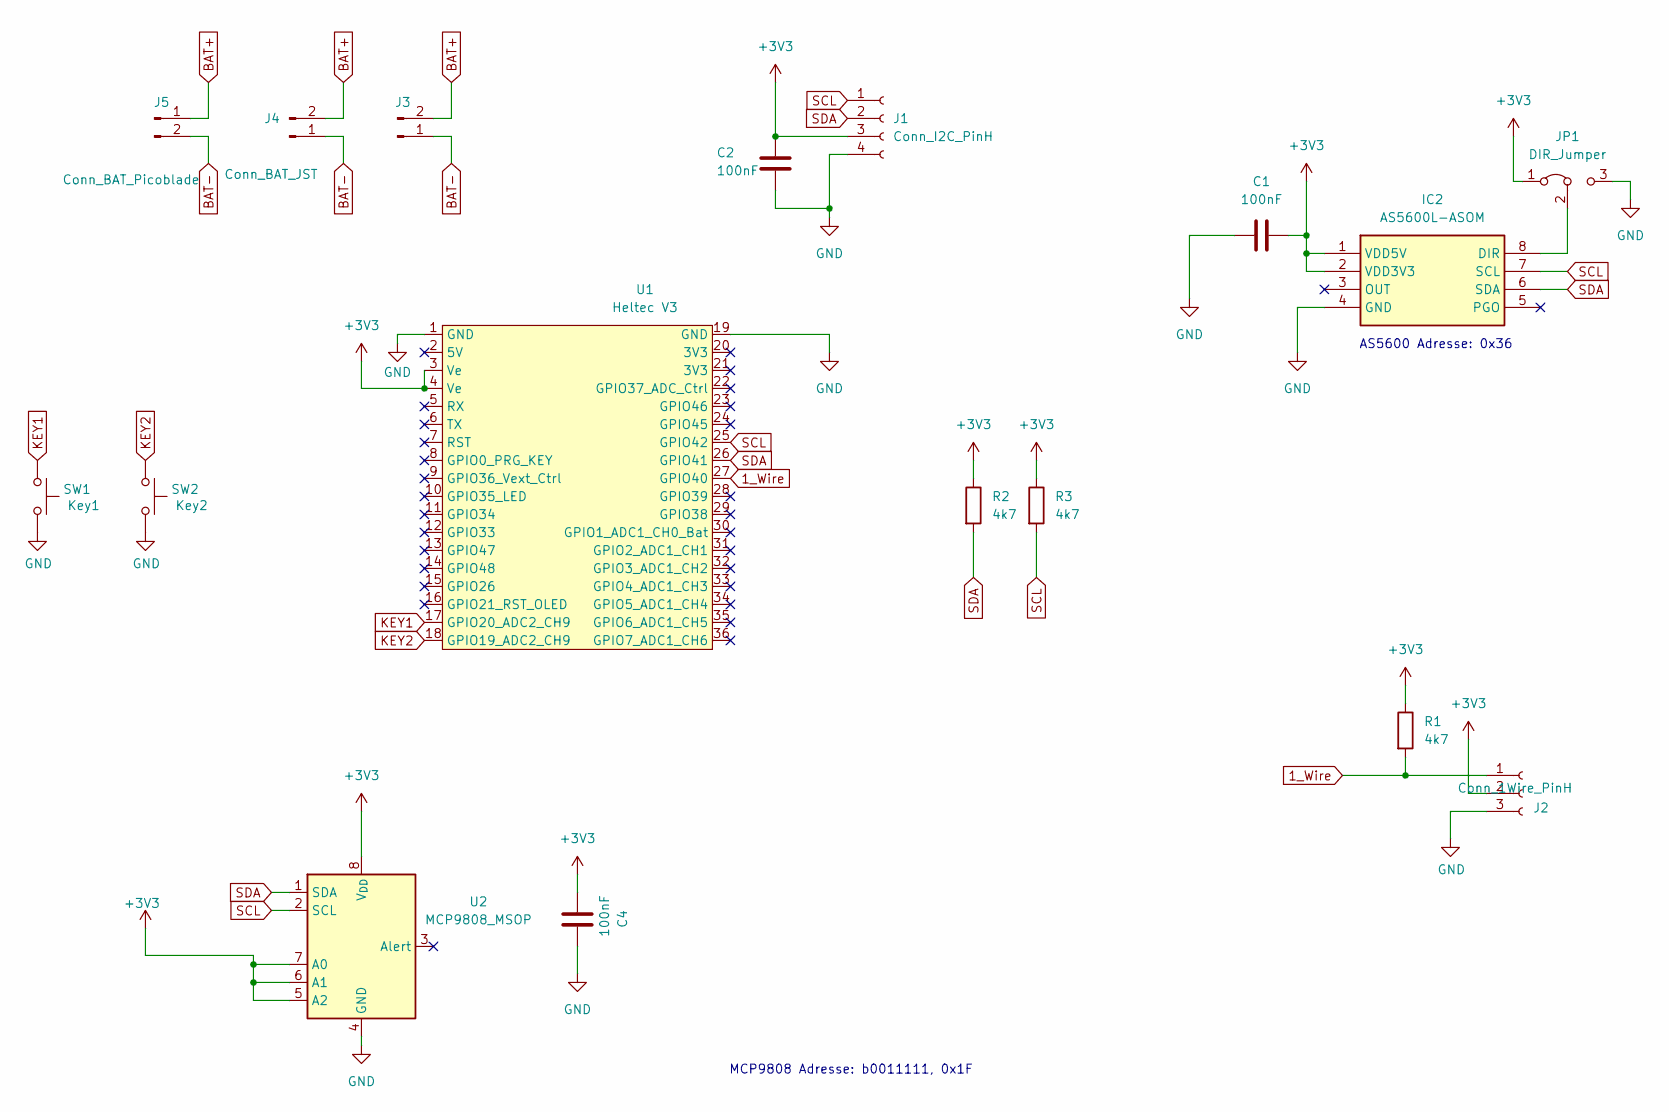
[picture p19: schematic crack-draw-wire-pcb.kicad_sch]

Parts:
C1, C2, C4: 100nF; C_0603_1608Metric
IC2: AS5600L-ASOM; SOIC127P600X175-8N; Mouser Part Number 985-AS5600L-ASOM
J1: Conn_I2C_PinH; PinHeader_1x04_P2.54mm_Vertical
J2: Conn_1Wire_PinH; PinHeader_1x03_P2.54mm_Vertical
J3, J4: Conn_BAT_JST; JST_PH_B2B-PH-K_1x02_P2.00mm_Vertical
J5: Conn_BAT_Picoblade; Molex_PicoBlade_53047-0210_1x02_P1.25mm_Vertical
JP1: DIR_Jumper; SolderJumper-3_P1.3mm_Open_Pad1.0x1.5mm
R1, R2, R3: 4k7; R_0603_1608Metric
SW1: Key1; SW_Push_SPST_NO_Alps_SKRK
SW2: Key2; SW_Push_SPST_NO_Alps_SKRK
U1: Heltec V3; Heltec_Wifi_LoRa_V3
U2: MCP9808_MSOP; MSOP-8_3x3mm_P0.65mm

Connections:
1_Wire: J2.1, R1.2, U1.27 (GPIO40)
+3V3: C1.2, C2.2, C4.1, IC2.1 (VDD5V), IC2.2 (VDD3V3), J1.3, J2.2, JP1.1 (A), R1.1, R2.1, R3.1, U1.3 (Ve), U1.4 (Ve), U2.5 (A2), U2.6 (A1), U2.7 (A0), U2.8 (V_{DD})
BAT+: J3.2, J4.2, J5.1
BAT-: J3.1, J4.1, J5.2
GND: C1.1, C2.1, C4.2, IC2.4 (GND), J1.4, J2.3, JP1.3 (B), SW1.1, SW2.1, U1.1 (GND), U1.19 (GND), U2.4 (GND)
KEY1: SW1.2, U1.17 (GPIO20_ADC2_CH9)
KEY2: SW2.2, U1.18 (GPIO19_ADC2_CH9)
unnamed: IC2.8 (DIR), JP1.2 (C)
SCL: IC2.7 (SCL), J1.1, R3.2, U1.25 (GPIO42), U2.2 (SCL)
SDA: IC2.6 (SDA), J1.2, R2.2, U1.26 (GPIO41), U2.1 (SDA)

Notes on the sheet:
MCP9808 Adresse: b0011111, 0x1F
AS5600 Adresse: 0x36

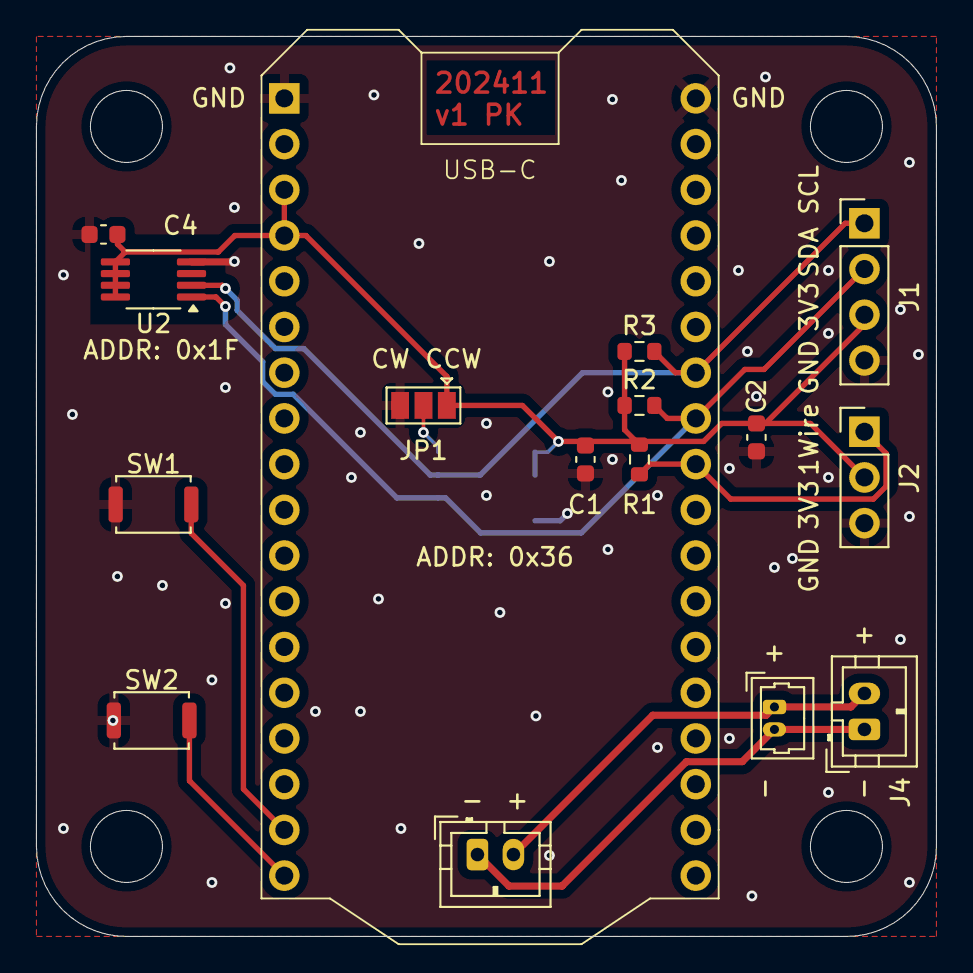
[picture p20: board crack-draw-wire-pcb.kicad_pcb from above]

Board: 2 copper layers, 50.0 x 50.0 mm, 17 parts (1 on the bottom side), 10 nets.

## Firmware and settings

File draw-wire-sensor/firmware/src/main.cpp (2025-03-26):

/**
 * Draw Wire Crack Monitoring Sensor
 * 
 * This code uses Rop Gonggrijps heltec_esp32_lora_v3 library and is based on 
 * the LoRaWAN_TTN.ino example, which is licensed under the MIT License.
 * 
 * If your NVS partition does not have stored TTN / LoRaWAN provisioning
 * information in it yet, you will be prompted for them on the serial port and
 * they will be stored for subsequent use.
 *
 * See https://github.com/ropg/LoRaWAN_ESP32
*/

#include <Arduino.h>
#include <Preferences.h>
#include <heltec_unofficial.h>
#include <LoRaWAN_ESP32.h>

// Pause between sends in seconds, so this is every 20 minutes. (Delay will be
// longer if regulatory or TTN Fair Use Policy requires it.)
#define MINIMUM_DELAY (20*60)

#define LENGTH 49400 //mm*1000, calibration length

// Function declarations
void goToSleep();
void radioInit();
void radioSend();
void getSensorData();
void encodePayload(uint8_t *uplinkData);
void printSensorData();
int16_t readRawAngle();
int32_t getPosition();
void resetZeroPosition();
float MCP9808readTemp();
uint8_t calculateCRC(uint8_t data[], uint8_t length);
void SHT45readTempHum(float &temperature, float &humidity);
void displayInfoFrame();
void check_nvs_data();
void calibration();


TwoWire I2C_Sensors = TwoWire(1);
LoRaWANNode* node;
int16_t state;
Preferences preferences;

const char* namespaceName = "crackMon";

// Pins
#define SDA_PIN 41
#define SCL_PIN 42
#define SW1_PIN 20
#define SW2_PIN 19

//AS5600 Hall Sensor
#define AS5600_I2C_ADDRESS 0x36
#define RAW_ANGLE_MSB 0x0C
#define RAW_ANGLE_LSB 0x0D

//MCP9808
#define MCP9808_ADDRESS 0x1F
#define MCP9808_TEMP_REGISTER 0x05
const float calibration_offset = -2;

//SHT45
#define SHT45_ADDRESS 0x44
#define CMD_MEASURE_HIGH_PRECISION 0xFD
#define CMD_SOFT_RESET 0x94

// OLED
bool display_flag = true; //set to false to save energy

// Sensor Data
float temp_pcb = -100.0;
float temp_ext = -100.0;
float hum_ext = 255;
int32_t pos = -100;
int16_t angle = -100;
int8_t bat = -100;

int16_t zero_pos = 100;

int16_t start_angle = 0; 
int16_t end_angle = 4096;
const int16_t gap_angle = 150;

void setup() {
  heltec_setup();
  heltec_ve(true);

  heltec_led(250);
  delay(50);
  heltec_led(0);

  delay(10);
  I2C_Sensors.begin(SDA_PIN, SCL_PIN, 400000);
  delay(100);
  pinMode(SW1_PIN,INPUT_PULLUP);
  pinMode(SW2_PIN,INPUT_PULLUP);
  check_nvs_data();
  if(digitalRead(SW1_PIN) == false) calibration();
  if(digitalRead(SW2_PIN) == false) resetZeroPosition();
  if(display_flag == false) display.displayOff();

  radioInit();
  getSensorData();
  if(display_flag == true) delay(2000);
  radioSend();

  goToSleep();    // Does not return, program starts over next round
}

void loop() {
  delay(100);
  // This is never called. There is no repetition: we always go back to
  // deep sleep one way or the other at the end of setup()
  getSensorData();
}

void radioInit() {
  both.println("Radio init");
  state = radio.begin();
  if (state != RADIOLIB_ERR_NONE) {
    both.println("Radio did not initialize. We'll try again later.");
    goToSleep();
  }

  node = persist.manage(&radio);

  if (!node->isActivated()) {
    both.println("Could not join network. We'll try again later.");
    heltec_led(30);
    delay(500);
    heltec_led(0);
    goToSleep();
  }
  // Manages uplink intervals to the TTN Fair Use Policy
  // https://avbentem.github.io/airtime-calculator/ttn/eu868/20
  node->setDutyCycle(true, 1250);
}

void radioSend(){
  uint8_t uplinkData[9];
  encodePayload(uplinkData);
  uint8_t downlinkData[256];
  size_t lenDown = sizeof(downlinkData);

  state = node->sendReceive(uplinkData, sizeof(uplinkData), 1, downlinkData, &lenDown);

  if(state == RADIOLIB_ERR_NONE) {
    both.println("Message sent, no downlink received.");
  } else if (state > 0) {
    both.println("Message sent, downlink received.");
  } else {
    both.printf("sendReceive returned error %d, we'll try again later.\n", state);
  }
}

void getSensorData() {
  uint8_t uplinkData[8];
  bat = heltec_battery_percent(-1);
  temp_pcb = MCP9808readTemp();
  pos = getPosition();
  SHT45readTempHum(temp_ext, hum_ext);
  if(display_flag) displayInfoFrame();

  // Generate sample hex data for decoding test in TTN dashboard
  //encodePayload(uplinkData);
  // for (int i = 0; i < sizeof(uplinkData); i++) {
  //   if (uplinkData[i] < 0x10) {
  //     Serial.print("0");
  //   }
  //   Serial.print(uplinkData[i], HEX);
  // }
  // Serial.println();
}

void encodePayload(uint8_t *uplinkData) {
    int16_t v2 = (int16_t)(temp_ext * 100);
    int16_t v3 = (uint8_t) hum_ext;
    int16_t v4 = (int16_t)(temp_pcb * 100);
    uplinkData[0] = pos >> 8;
    uplinkData[1] = pos & 0xFF;
    uplinkData[2] = v2 >> 8;
    uplinkData[3] = v2 & 0xFF;
    uplinkData[4] = v3;
    uplinkData[5] = v4 >> 8;
    uplinkData[6] = v4 & 0xFF;
    uplinkData[7] = bat;
    uplinkData[8] = angle >> 8;
    uplinkData[9] = angle & 0xFF;
}

void goToSleep() {
  // allows recall of the session after deepsleep
  persist.saveSession(node);
  // Calculate minimum duty cycle delay (per FUP & law!)
  uint32_t interval = node->timeUntilUplink();
  // And then pick it or our MINIMUM_DELAY, whichever is greater
  uint32_t delayMs = max(interval, ((uint32_t)MINIMUM_DELAY * 1000));
  if(display_flag){
    both.printf("Going to deep sleep now. Next TX in %i min\n", delayMs/(1000*60));
    delay(1000);  // So message prints
  }
  // and off to bed we go
  heltec_deep_sleep((delayMs-millis())/1000); // -millis() to subtract the process time
}

int16_t readRawAngle() {
    I2C_Sensors.beginTransmission(AS5600_I2C_ADDRESS);
    I2C_Sensors.write(RAW_ANGLE_MSB);
    if (I2C_Sensors.endTransmission(false) != 0) {
        both.println("AS5600 com. error_1!");
        return 0xFFFF;
    }

    if (I2C_Sensors.requestFrom(AS5600_I2C_ADDRESS, 2) != 2) {
        both.println("AS5600 com. error_2!");
        return 0xFFFF; 
    }

    uint8_t msb = I2C_Sensors.read();
    uint8_t lsb = I2C_Sensors.read();
    uint16_t raw_angle = (msb << 8) | lsb;
    // Serial.print("Raw Angle: ");
    // Serial.println(raw_angle);
    return raw_angle;
}

int32_t getPosition(){
  int32_t angle_ = readRawAngle() - start_angle;
  if (angle_ < -gap_angle) angle_ = angle_ + 4096;
  angle = angle_ + start_angle;
  int32_t raw_pos = map(angle_, 0, end_angle, 0, LENGTH);
  return (raw_pos - zero_pos);
}

void resetZeroPosition() {
  if (!preferences.begin(namespaceName, false)) { // false = Read-Write
    Serial.println("Failed to open preferences in write mode");
    delay(1000);
    return;
  }
  zero_pos = 0;
  zero_pos = getPosition();
  both.print("New zero_pos: ");
  both.println(zero_pos);
  preferences.putInt("zero_pos", zero_pos);
  preferences.end();
  delay(1000);
}

float MCP9808readTemp() {
  I2C_Sensors.beginTransmission(MCP9808_ADDRESS);
  I2C_Sensors.write(MCP9808_TEMP_REGISTER);
  if (I2C_Sensors.endTransmission() != 0) {
    both.println("MCP9808 com error!");
    return NAN;
  }

  I2C_Sensors.requestFrom(MCP9808_ADDRESS, 2);
  if (I2C_Sensors.available() == 2) {
    uint8_t msb = I2C_Sensors.read();
    uint8_t lsb = I2C_Sensors.read();

    int16_t rawTemp = ((msb << 8) | lsb) & 0x0FFF;
    if (msb & 0x10) { //if negative
      rawTemp -= 4096;
    }

    float temperature = rawTemp * 0.0625 + 1;
    return temperature + calibration_offset;
  }

  return NAN;
}

uint8_t calculateCRC(uint8_t data[], uint8_t length) {
    uint8_t crc = 0xFF;
    for (uint8_t i = 0; i < length; i++) {
        crc ^= data[i];
        for (uint8_t j = 0; j < 8; j++) {
            if (crc & 0x80) {
                crc = (crc << 1) ^ 0x31;
            } else {
                crc = (crc << 1);
            }
        }
    }
    return crc;
}

void SHT45readTempHum(float &temperature, float &humidity) {
    I2C_Sensors.beginTransmission(SHT45_ADDRESS);
    I2C_Sensors.write(CMD_MEASURE_HIGH_PRECISION);
    if (I2C_Sensors.endTransmission() != 0) {
        //both.println("SHT45 com error!");
        temperature = -100;
        humidity = -100;
        return;
    }
    delay(10); // Wait for the measurement

    I2C_Sensors.requestFrom(SHT45_ADDRESS, 6);
    uint8_t tempMSB = I2C_Sensors.read();
    uint8_t tempLSB = I2C_Sensors.read();
    uint8_t tempCRC = I2C_Sensors.read();
    uint8_t humMSB = I2C_Sensors.read();
    uint8_t humLSB = I2C_Sensors.read();
    uint8_t humCRC = I2C_Sensors.read();

    // CRC-check
    uint8_t tempData[] = {tempMSB, tempLSB};
    if (calculateCRC(tempData, 2) != tempCRC) {
        both.println("Temp CRC error");
        temperature = NAN;
    }

    // CRC-check
    uint8_t humData[] = {humMSB, humLSB};
    if (calculateCRC(humData, 2) != humCRC) {
        both.println("Hum CRC error");
        humidity = NAN;
    }

    uint16_t rawTemp = (tempMSB << 8) | tempLSB;
    uint16_t rawHum = (humMSB << 8) | humLSB;

    temperature = -45.0 + 175.0 * (rawTemp / 65535.0);
    humidity = -6.0 + 125.0 * (rawHum / 65535.0);
}

void displayInfoFrame() {
  display.clear();
  display.setTextAlignment(TEXT_ALIGN_LEFT);
  display.setFont(ArialMT_Plain_10);

  int16_t y_pos = 0;

  String posStr = "Pos: " + String((float)pos/1000.0, 3) + " mm";
  display.drawString(0, y_pos, posStr);
  y_pos += 12;

  // String angleStr = "Angle: " + String(angle);
  // display.drawString(0, y_pos, angleStr);
  // y_pos += 12;

  String batStr = "BAT: " + String(bat) + " %";
  display.drawString(0, y_pos, batStr);
  y_pos += 12;

  String pcbStr = "PCB: " + String(temp_pcb, 1) + " °C";
  display.drawString(0, y_pos, pcbStr);
  y_pos += 12;

  String extStr = "EXT: " + String(temp_ext, 1) + " °C, " + String(hum_ext, 0) + " %";
  display.drawString(0, y_pos, extStr);

  display.display();
}

void check_nvs_data() {
  // Open the Namespace in READONLY mode
  if (!preferences.begin(namespaceName, true)) { // true = Read-Only
    Serial.println("Failed to open preferences");
    return;
  }

  // Check if the start_angle exists 
  if (preferences.isKey("start_angle")) {
    // "start_angle" exists, read the value
    start_angle = preferences.getInt("start_angle", start_angle);
    end_angle = preferences.getInt("end_angle", end_angle);
    zero_pos = preferences.getInt("zero_pos", zero_pos);
    Serial.print("nvs start_angle: ");
    Serial.println(start_angle);
    Serial.print("nvs end_angle: ");
    Serial.println(end_angle);
    Serial.print("nvs zero_pos: ");
    Serial.println(zero_pos);
  } else {
    both.println("No nvs calibration data");
    preferences.end();
    calibration();
  }

  // Close Preferences
  preferences.end();
}

void calibration() {
  both.println("Calibration started!");
  // Wait until SW2 is released
  while(digitalRead(SW2_PIN) == false) {
    delay(20);
  }
  both.println("Press SW2 to set start pos.");
  while(digitalRead(SW2_PIN) == true) {
    delay(20);
  }
  if (!preferences.begin(namespaceName, false)) {
    both.println("Failed to open preferences in write mode");
    delay(1000);
    return;
  }
  start_angle = readRawAngle();
  preferences.putInt("start_angle", start_angle);
  both.print("New start angle: ");
  both.println(start_angle);

  delay(500);
  while(digitalRead(SW2_PIN) == false) {
    delay(20);
  }
  both.println("Press SW2 to set end pos.");
  while(digitalRead(SW2_PIN) == true) {
    delay(20);
  }
  end_angle = readRawAngle() - start_angle;
  if (end_angle < 0) end_angle = end_angle + 4096;
  preferences.putInt("end_angle", end_angle);
  both.print("New end angle: ");
  both.println(end_angle);

  delay(500);
  while(digitalRead(SW2_PIN) == false) {
    delay(20);
  }
  both.println("Press SW2 to set zero pos.");
  while(digitalRead(SW2_PIN) == true) {
    delay(20);
  }
  zero_pos = 0;
  zero_pos = getPosition();
  preferences.putInt("zero_pos", zero_pos);
  both.print("New zero pos: ");
  both.println(zero_pos);
  preferences.end();

  delay(5000);
  both.println("Calibration done!");
}
